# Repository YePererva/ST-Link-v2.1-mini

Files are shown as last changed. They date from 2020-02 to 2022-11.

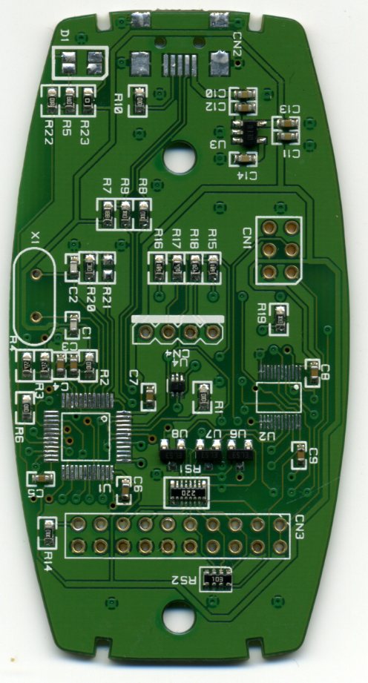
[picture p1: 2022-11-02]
references/project-of-other/top.jpg

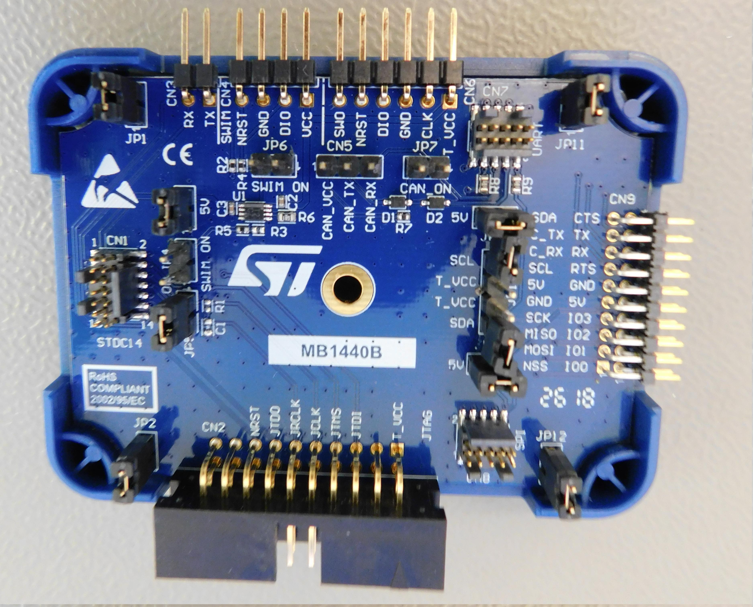
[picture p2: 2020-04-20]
references/St-Link v3/STLink-V3-Board-Large.jpg

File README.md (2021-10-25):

# ST-Link v2.1 - mini

** Status ** : Unfinished and deprecated due to obtaining the [STLink V3 mini](https://www.st.com/en/development-tools/stlink-v3mini.html)

The idea of this project came, when I broke my [NUCLEO-L432KC](https://www.st.com/content/st_com/en/products/evaluation-tools/product-evaluation-tools/mcu-mpu-eval-tools/stm32-mcu-mpu-eval-tools/stm32-nucleo-boards/nucleo-l432kc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) board and thought if I can cannibalize the leftovers of it and make a replacement PCB, where I can transplant the microcontroller and keep using the chip from Nucleo board as a dedicated STLink programmer.

This repository has no purpose or instructions for hacking the firmware or any other part of STLink!

Although, the schematic of original [NUCLEO-L432KC](https://www.st.com/resource/en/data_brief/nucleo-l432kc.pdf) and its STLink part is available [on STMicroelectronics website](https://www.st.com/resource/en/schematic_pack/nucleo-32pins_sch.zip) it has few points that I don't like:
- it uses USB-micro, while USB type C seems to be more appropriate
- STMicroelectronics introduced the `STCD-14` connector for STM32 programming (via SWD + VCP). It would be nice to have it
- official firmware allows to switch device between programming the STM32 and STM8 microcontrollers
- the [Black Magic Probe](https://github.com/blacksphere/blackmagic/wiki) is another popular programming / debugging tool and have a [firmware](https://github.com/blacksphere/blackmagic/tree/master/src/platforms/stlink), compatible with STM32F103CxT6 microcontroller. It may be reasonable to have a programming interface to convert this DIY STLink into BMP later in future.
- can't power-up the target microcontroller from STLink.

## What is inside of repository
- `datasheets`: \
  datasheets for microcontroller, USB type Connector, etc.
- `project files`:
  - `simplified`: \
    simplified version of STLink without EDS protection of either USB or SWD / SWIM / VCP
  - `protected`: \
    version with EDS protection
  - `STDC14-adapters`: \
    The STLink V3 mini can't be connected directly to devboards alike BluePill, etc. due to different connector pinout and size. Here are 2 connectors for STDC14 : as breadboard breakout board and as plug-&-play connector to SWD interface on BluePill board.
- `references`: \
    references on stuff like pinout of programming interfaces, STLinks made by other people, etc.

### Similar projects

- https://github.com/MartinD-CZ/ST-Link-V21-clone

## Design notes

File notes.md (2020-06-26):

# STDC14 as SWD + USART interface
STM suggests SAMTEC FTSH-107-01-L-DV-K-A as STDC14 connector.

Pinout is

| Pin # | Description | Pin # | Description |
| --- | --- | --- | --- |
| 1 | Reserved | 2 | Reserved |
| 3 | Target Vcc | 4 | T_JTMS/T_SWDIO |
| 5 | GND | 6 | T_JRCLK/T_SWCLK |
| 7 | GND | 8 | T_JDIO / T_SWO |
| 9 | T_JRCLK / NC | 10 | T_JTDI / NC |
| 11 | GND detect | 12 | T_NRST |
| 13 | T_VCP_RX (ST_LINK_TX) | 14 | T_VCP_TX (ST_LINK_RX) |

Reserved pins - not connected on target side
Target VCC doesn't provide power to target board. It is ST-link reference to indicate that target is powered.

# STDC14 and 10 Pin Cortex arm debug connector to STM32F103C8T6 BluePill
https://stackoverflow.com/questions/57538832/how-to-connect-stlink-v3mini-to-a-blue-pill

# STDC14 as SWD + UART on target side

| Pin # | Description | Pin # | Description |
| --- | --- | --- | --- |
| 1 | NC | 2 | NC |
| 3 | Vcc | 4 | SWDIO |
| 5 | GND | 6 | SWCLK |
| 7 | GND | 8 | SWO |
| 9 |  NC | 10 | Not connected |
| 11 | Pull to GND 100 Ohm | 12 | NRST |
| 13 | RX | 14 | TX |

`NC` : Not Connected

# STDC14 as SWD + UART on STLINK side

| Pin # | Description | Pin # | Description |
| --- | --- | --- | --- |
| 1 | NC | 2 | NC |
| 3 | Vcc | 4 | SWDIO |
| 5 | GND | 6 | SWCLK |
| 7 | GND | 8 | SWO |
| 9 |  NC | 10 | Not connected |
| 11 | Pull to GND with 100 Ohm | 12 | NRST |
| 13 | TX | 14 | RX |

`NC` : Not Connected

# STDC14 as JTAG

| Pin # | Description | Pin # | Description |
| --- | --- | --- | --- |
| 1 | NC | 2 | NC |
| 3 | Target Vcc | 4 | T_JTMS |
| 5 | GND | 6 | T_JCLK |
| 7 | GND | 8 | T_JDIO |
| 9 | T_JRCLK | 10 | T_JTDI |
| 11 | Pull to GND with 100 Ohm | 12 | T_NRST |
| 13 | NC | 14 | NC |

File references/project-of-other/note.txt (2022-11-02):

Schematic has mistake: R1 should got to GND, not 3.3V

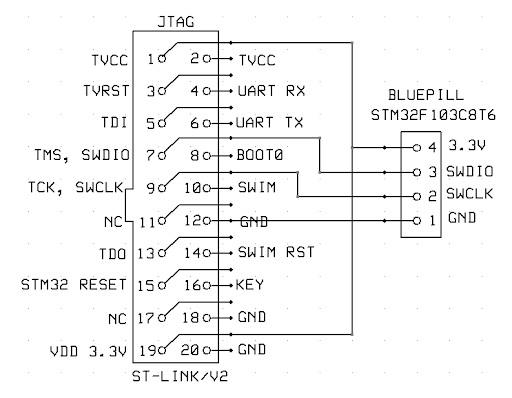
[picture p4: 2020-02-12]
references/JTAG/JTAG to BluePill.png

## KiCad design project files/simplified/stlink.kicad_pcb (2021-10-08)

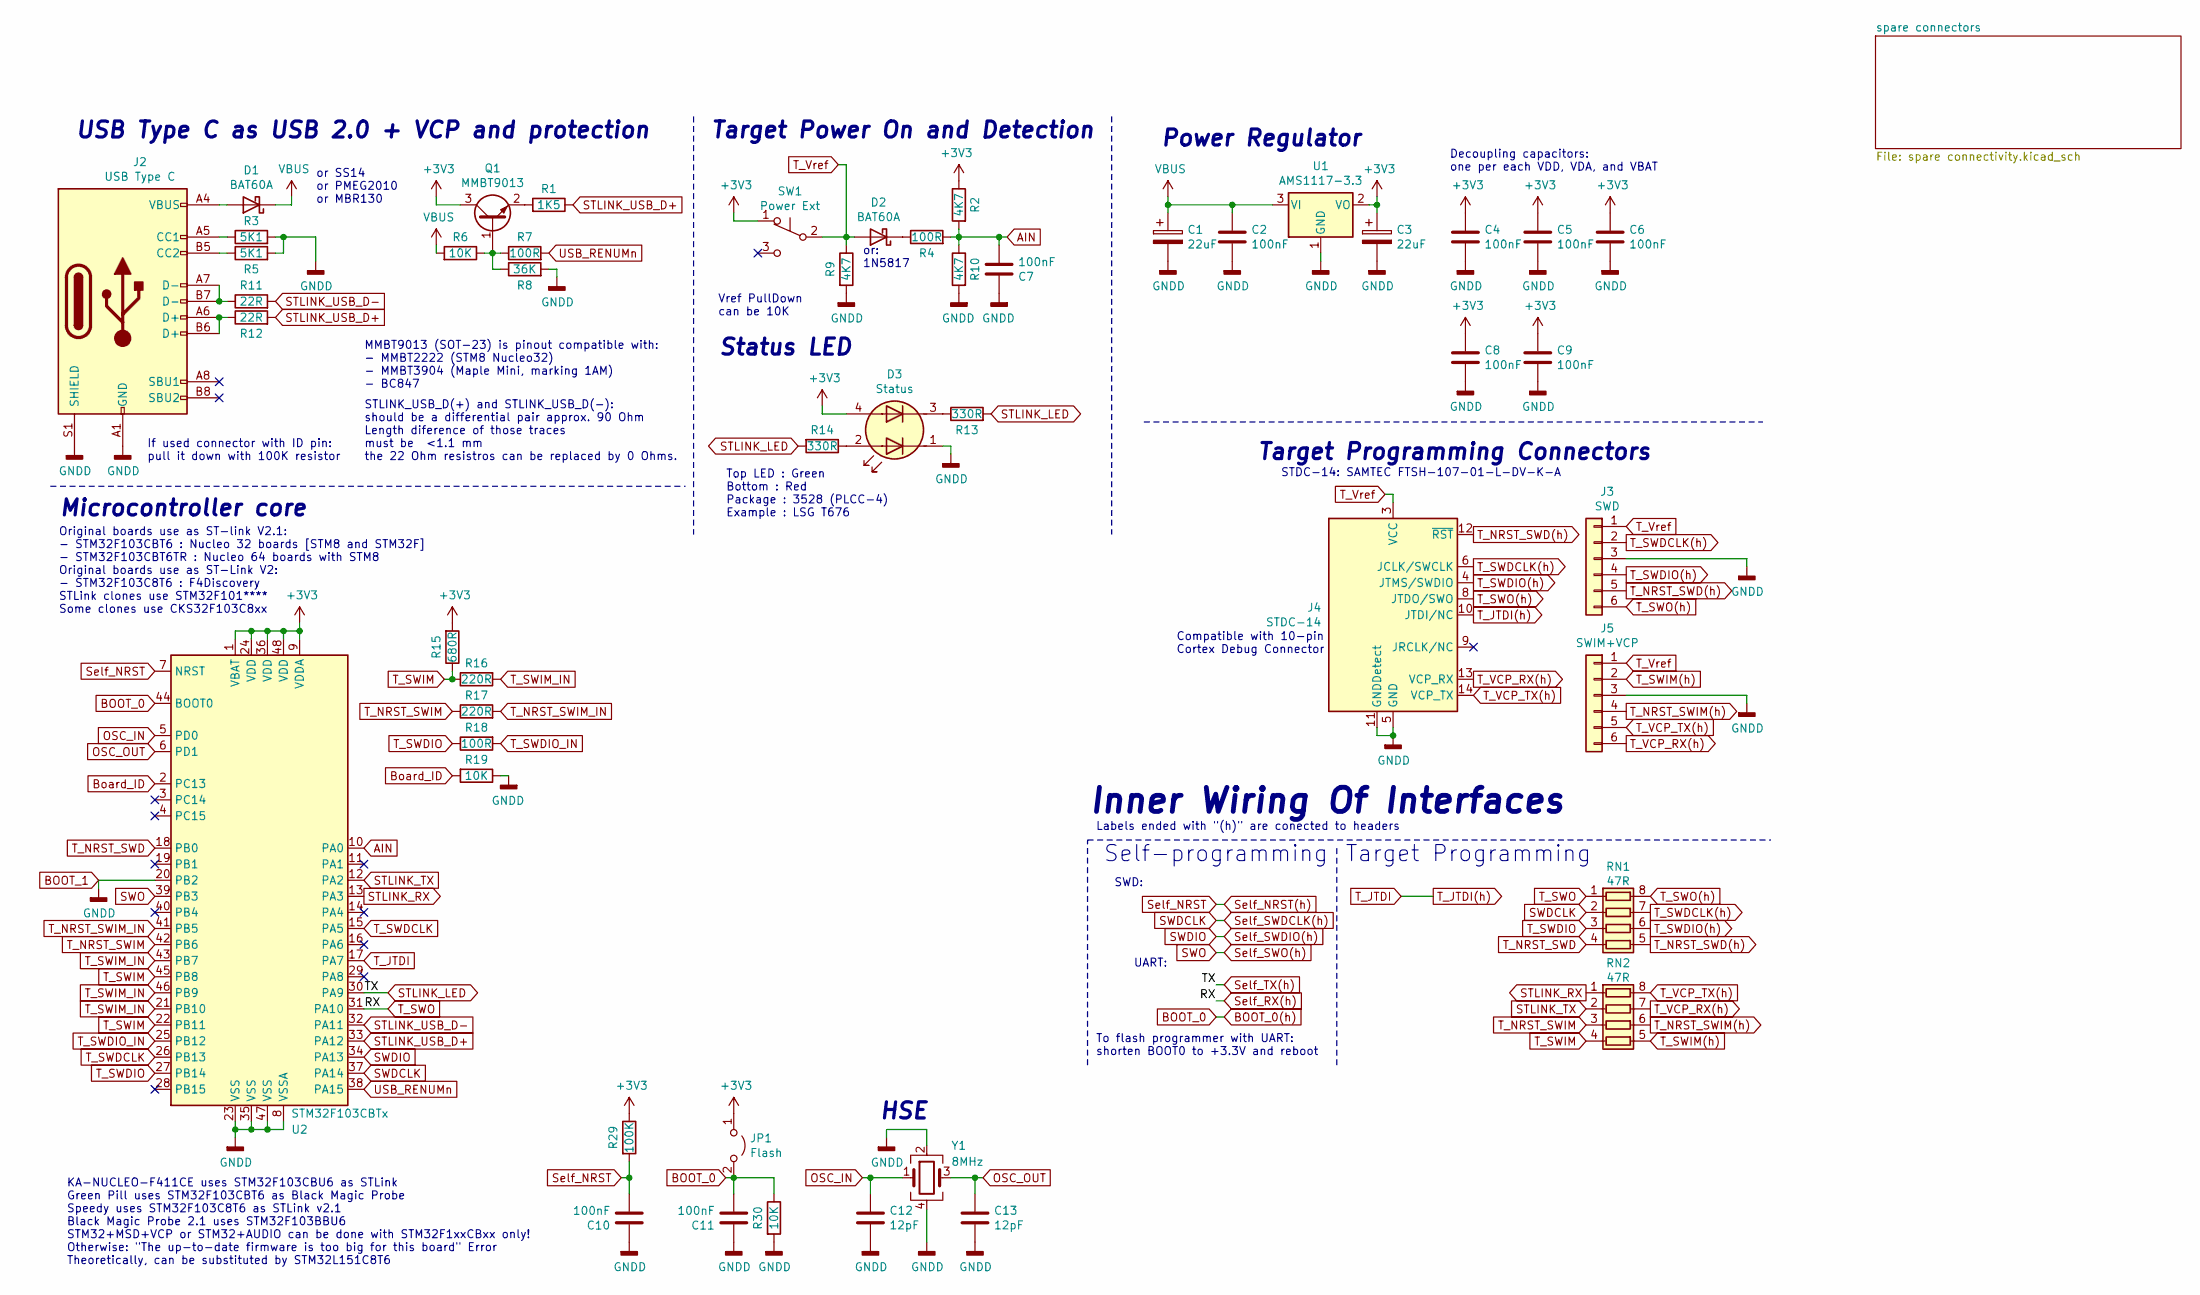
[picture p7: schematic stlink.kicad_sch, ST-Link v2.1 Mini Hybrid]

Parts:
C1, C3: 22uF; CP_EIA-7343-30_AVX-N
C2, C4, C5, C6, C7, C8, C9, C10, C11: 100nF; C_0603_1608Metric
C12, C13: 12pF; C_0603_1608Metric
D1, D2: BAT60A; D_SOD-323
D3: Status; LED_Avago_PLCC4_3.2x2.8mm_CW
J2: USB Type C; USB_C_Receptacle_Palconn_UTC16-G
J3: SWD; PinHeader_1x06_P2.54mm_Vertical
J4: STDC-14; PinHeader_2x07_P1.27mm_Vertical_SMD
J5: SWIM+VCP; PinHeader_1x06_P2.54mm_Vertical
JP1: Flash; PinSocket_2x01_P1.27mm_Vertical
Q1: MMBT9013; SOT-23
R1: 1K5; R_0603_1608Metric
R2, R9, R10: 4K7; R_0603_1608Metric
R3, R5: 5K1; R_0603_1608Metric
R4, R7, R18: 100R; R_0603_1608Metric
R6, R19, R30: 10K; R_0603_1608Metric
R8: 36K; R_0603_1608Metric
R11, R12: 22R; R_0603_1608Metric
R13, R14: 330R; R_0603_1608Metric
R15: 680R; R_0603_1608Metric
R16, R17: 220R; R_0603_1608Metric
R29: 100K; R_0603_1608Metric
RN1, RN2: 47R
SW1: Power Ext
U1: AMS1117-3.3; SOT-223-3_TabPin2
U2: STM32F103CBTx; LQFP-48_7x7mm_P0.5mm
Y1: 8MHz; Crystal_SMD_Abracon_ABM8G-4Pin_3.2x2.5mm

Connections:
AIN: C7.2, R2.2, R4.2, R10.1, U2.10 (PA0); also elsewhere on the board
BOOT_0: C11.2, JP1.2 (B), R30.1, U2.44 (BOOT0); also elsewhere on the board
BOOT_1: C1.2, C2.2, C3.2, C4.2, C5.2, C6.2, C7.1, C8.2, C9.2, C10.1, C11.1, C12.2, C13.2, D3.1 (A1), J2.A1 (GND), J2.A12 (GND), J2.B1 (GND), J2.B12 (GND), J2.S1 (SHIELD), J3.3, J4.5 (GND), J4.7 (GND), J4.11 (GNDDetect), J5.3, R3.2, R5.2, R8.2, R9.2, R10.2, R19.1, R30.2, U1.1 (GND), U2.8 (VSSA), U2.20 (PB2), U2.23 (VSS), U2.35 (VSS), U2.47 (VSS), Y1.2, Y1.4; also elsewhere on the board
Board_ID: R19.2, U2.2 (PC13); also elsewhere on the board
unnamed: D1.2 (A), J2.A4 (VBUS), J2.A9 (VBUS), J2.B4 (VBUS), J2.B9 (VBUS)
unnamed: D2.1 (K), R4.1
unnamed: D3.2 (K1), R14.1
unnamed: D3.3 (A2), R13.1
unnamed: J2.A5 (CC1), R3.1
unnamed: J2.A6 (D+), J2.B6 (D+), R12.1
unnamed: J2.A7 (D-), J2.B7 (D-), R11.1
unnamed: J2.B5 (CC2), R5.1
unnamed: Q1.1 (B), R6.1, R7.1, R8.1
unnamed: Q1.2 (E), R1.2
OSC_IN: C12.1, U2.5 (PD0), Y1.1; also elsewhere on the board
OSC_OUT: C13.1, U2.6 (PD1), Y1.3; also elsewhere on the board
STLINK_LED: R13.2, R14.2, U2.30 (PA9); also elsewhere on the board
STLINK_RX: RN2.1 (R1.1), U2.13 (PA3); also elsewhere on the board
STLINK_TX: RN2.2 (R2.1), U2.12 (PA2); also elsewhere on the board
STLINK_USB_D+: R1.1, R12.2, U2.33 (PA12); also elsewhere on the board
STLINK_USB_D-: R11.2, U2.32 (PA11); also elsewhere on the board
SWDCLK: RN1.2 (R2.1), U2.37 (PA14); also elsewhere on the board
SWDIO: U2.34 (PA13); also elsewhere on the board
SWO: U2.39 (PB3); also elsewhere on the board
Self_NRST: C10.2, R29.2, U2.7 (NRST); also elsewhere on the board
Self_RX(h): RN1.1 (R1.1), U2.31 (PA10); also elsewhere on the board
T_JTDI: J4.10 (JTDI/NC), U2.17 (PA7); also elsewhere on the board
T_NRST_SWD: RN1.4 (R4.1), U2.18 (PB0); also elsewhere on the board
T_NRST_SWD(h): J3.5, J4.12 (~RST), RN1.5 (R4.2)
T_NRST_SWIM: R17.1, RN2.3 (R3.1), U2.42 (PB6); also elsewhere on the board
T_NRST_SWIM(h): J5.4, RN2.6 (R3.2)
T_NRST_SWIM_IN: R17.2, U2.41 (PB5); also elsewhere on the board
T_SWDCLK: U2.15 (PA5), U2.26 (PB13); also elsewhere on the board
T_SWDCLK(h): J3.2, J4.6 (JCLK/SWCLK), RN1.7 (R2.2)
T_SWDIO: R18.1, RN1.3 (R3.1), U2.27 (PB14); also elsewhere on the board
T_SWDIO(h): J3.4, J4.4 (JTMS/SWDIO), RN1.6 (R3.2)
T_SWDIO_IN: R18.2, U2.25 (PB12); also elsewhere on the board
T_SWIM: R15.1, R16.1, RN2.4 (R4.1), U2.22 (PB11), U2.45 (PB8); also elsewhere on the board
T_SWIM(h): J5.2, RN2.5 (R4.2)
T_SWIM_IN: R16.2, U2.21 (PB10), U2.43 (PB7), U2.46 (PB9); also elsewhere on the board
T_SWO(h): J3.6, J4.8 (JTDO/SWO), RN1.8 (R1.2)
T_VCP_RX(h): J4.13 (VCP_RX), J5.6, RN2.7 (R2.2)
T_VCP_TX(h): J4.14 (VCP_TX), J5.5, RN2.8 (R1.2)
T_Vref: D2.2 (A), J3.1, J4.3 (VCC), J5.1, R9.1, SW1.2 (B)
USB_RENUMn: R7.2, U2.38 (PA15); also elsewhere on the board
VBUS: C1.1, C2.1, D1.1 (K), R6.2, U1.3 (VI)

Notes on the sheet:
Microcontroller core
Original boards use as ST-link V2.1: - STM32F103CBT6 : Nucleo 32 boards [STM8 and STM32F] - STM32F103CBT6TR : Nucleo 64 boards with STM8 Original boards use as ST-Link V2: - STM32F103C8T6 : F4Discovery STLink clones use STM32F101**** Some clones use CKS32F103C8xx
KA-NUCLEO-F411CE uses STM32F103CBU6 as STLink Green Pill uses STM32F103CBT6 as Black Magic Probe Speedy uses STM32F103C8T6 as STLink v2.1 Black Magic Probe 2.1 uses STM32F103BBU6 STM32+MSD+VCP or STM32+AUDIO can be done with STM32F1xxCBxx only! Otherwise: "The up-to-date firmware is too big for thi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
USB Type C as USB 2.0 + VCP and protection
If used connector with ID pin: pull it down with 100K resistor
or SS14 or PMEG2010 or MBR130
MMBT9013 (SOT-23) is pinout compatible with: - MMBT2222 (STM8 Nucleo32) - MMBT3904 (Maple Mini, marking 1AM) - BC847
STLINK_USB_D(+) and STLINK_USB_D(-): should be a differential pair approx. 90 Ohm Length diference of those traces must be <1.1 mm the 22 Ohm resistros can be replaced by 0 Ohms.
Target Power On and Detection
Vref PullDown can be 10K
Status LED
Top LED : Green Bottom : Red Package : 3528 (PLCC-4) Example : LSG T676
or: 1N5817
HSE
Inner Wiring Of Interfaces
Labels ended with "(h)" are conected to headers
To flash programmer with UART: shorten BOOT0 to +3.3V and reboot
SWD:
Power Regulator
UART:
Compatible with 10-pin Cortex Debug Connector
Target Programming Connectors
STDC-14: SAMTEC FTSH-107-01-L-DV-K-A
Self-programming
Target Programming
Decoupling capacitors: one per each VDD, VDA, and VBAT

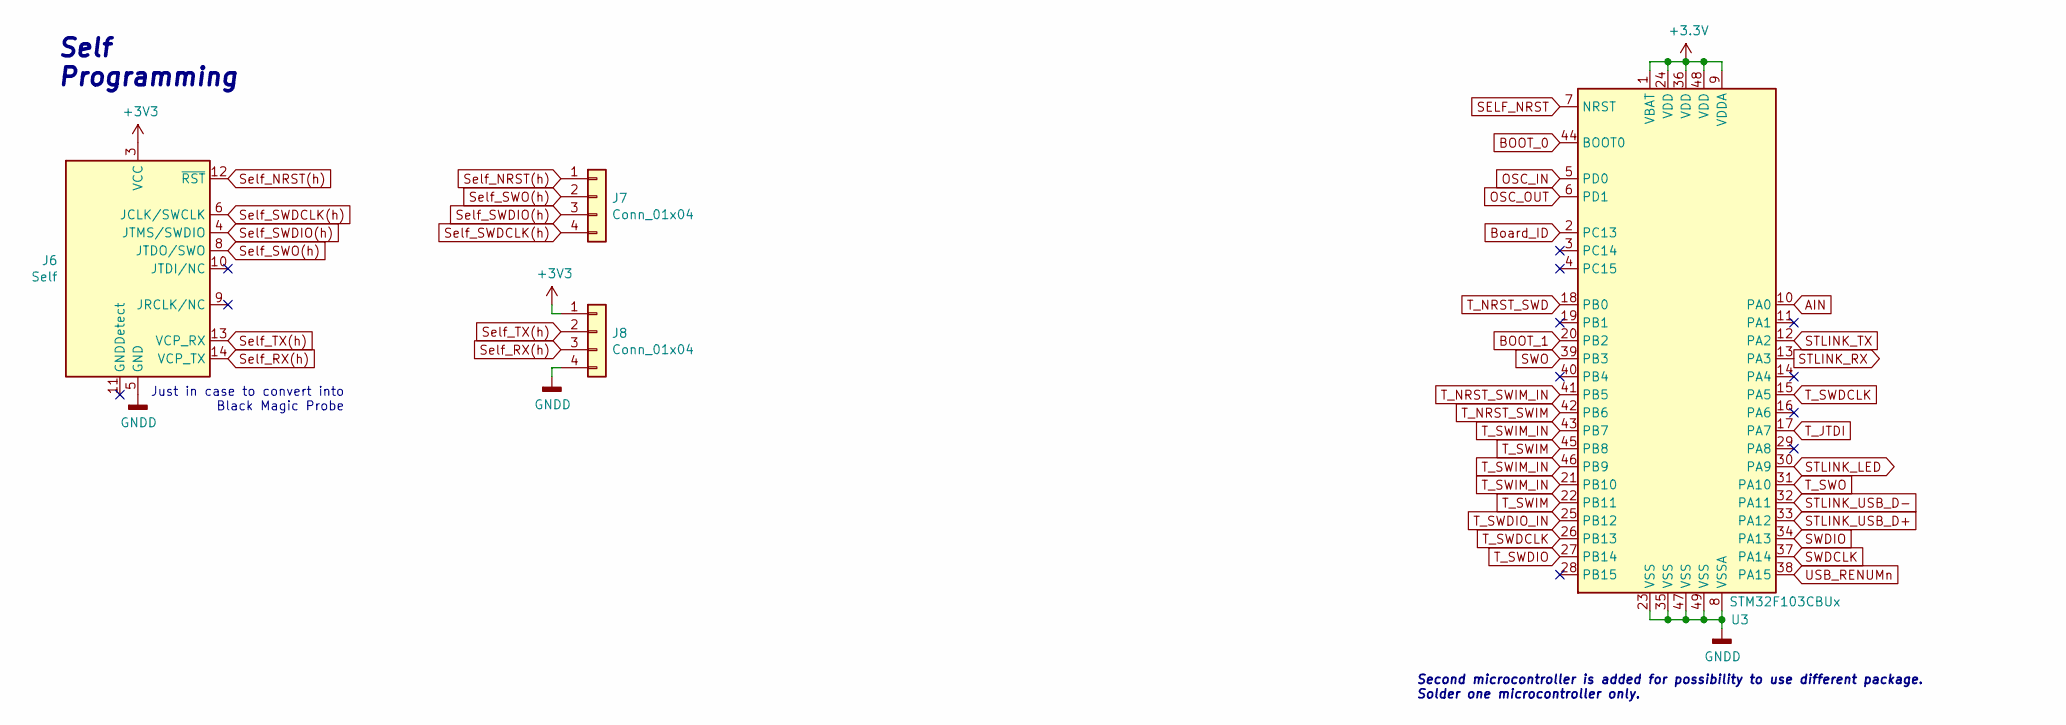
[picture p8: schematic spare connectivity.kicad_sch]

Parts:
J6: Self; PinHeader_2x07_P1.27mm_Vertical_SMD
J7, J8: Conn_01x04; PinHeader_1x04_P2.54mm_Vertical
U3: STM32F103CBUx; QFN-48-1EP_7x7mm_P0.5mm_EP5.6x5.6mm

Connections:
AIN: U3.10 (PA0); also elsewhere on the board
BOOT_0: U3.44 (BOOT0); also elsewhere on the board
BOOT_1: J6.5 (GND), J6.7 (GND), J8.4, U3.8 (VSSA), U3.20 (PB2), U3.23 (VSS), U3.35 (VSS), U3.47 (VSS), U3.49 (VSS); also elsewhere on the board
Board_ID: U3.2 (PC13); also elsewhere on the board
OSC_IN: U3.5 (PD0); also elsewhere on the board
OSC_OUT: U3.6 (PD1); also elsewhere on the board
SELF_NRST: U3.7 (NRST)
STLINK_LED: J6.13 (VCP_RX), J8.2, U3.30 (PA9); also elsewhere on the board
STLINK_RX: U3.13 (PA3); also elsewhere on the board
STLINK_TX: U3.12 (PA2); also elsewhere on the board
STLINK_USB_D+: U3.33 (PA12); also elsewhere on the board
STLINK_USB_D-: U3.32 (PA11); also elsewhere on the board
SWDCLK: J6.6 (JCLK/SWCLK), J7.4, U3.37 (PA14); also elsewhere on the board
SWDIO: J6.4 (JTMS/SWDIO), J7.3, U3.34 (PA13); also elsewhere on the board
SWO: J6.8 (JTDO/SWO), J7.2, U3.39 (PB3); also elsewhere on the board
Self_NRST: J6.12 (~RST), J7.1; also elsewhere on the board
Self_RX(h): J6.14 (VCP_TX), J8.3, U3.31 (PA10); also elsewhere on the board
T_JTDI: U3.17 (PA7); also elsewhere on the board
T_NRST_SWD: U3.18 (PB0); also elsewhere on the board
T_NRST_SWIM: U3.42 (PB6); also elsewhere on the board
T_NRST_SWIM_IN: U3.41 (PB5); also elsewhere on the board
T_SWDCLK: U3.15 (PA5), U3.26 (PB13); also elsewhere on the board
T_SWDIO: U3.27 (PB14); also elsewhere on the board
T_SWDIO_IN: U3.25 (PB12); also elsewhere on the board
T_SWIM: U3.22 (PB11), U3.45 (PB8); also elsewhere on the board
T_SWIM_IN: U3.21 (PB10), U3.43 (PB7), U3.46 (PB9); also elsewhere on the board
USB_RENUMn: U3.38 (PA15); also elsewhere on the board

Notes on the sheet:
Self Programming
Just in case to convert into Black Magic Probe
Second microcontroller is added for possibility to use different package. Solder one microcontroller only.

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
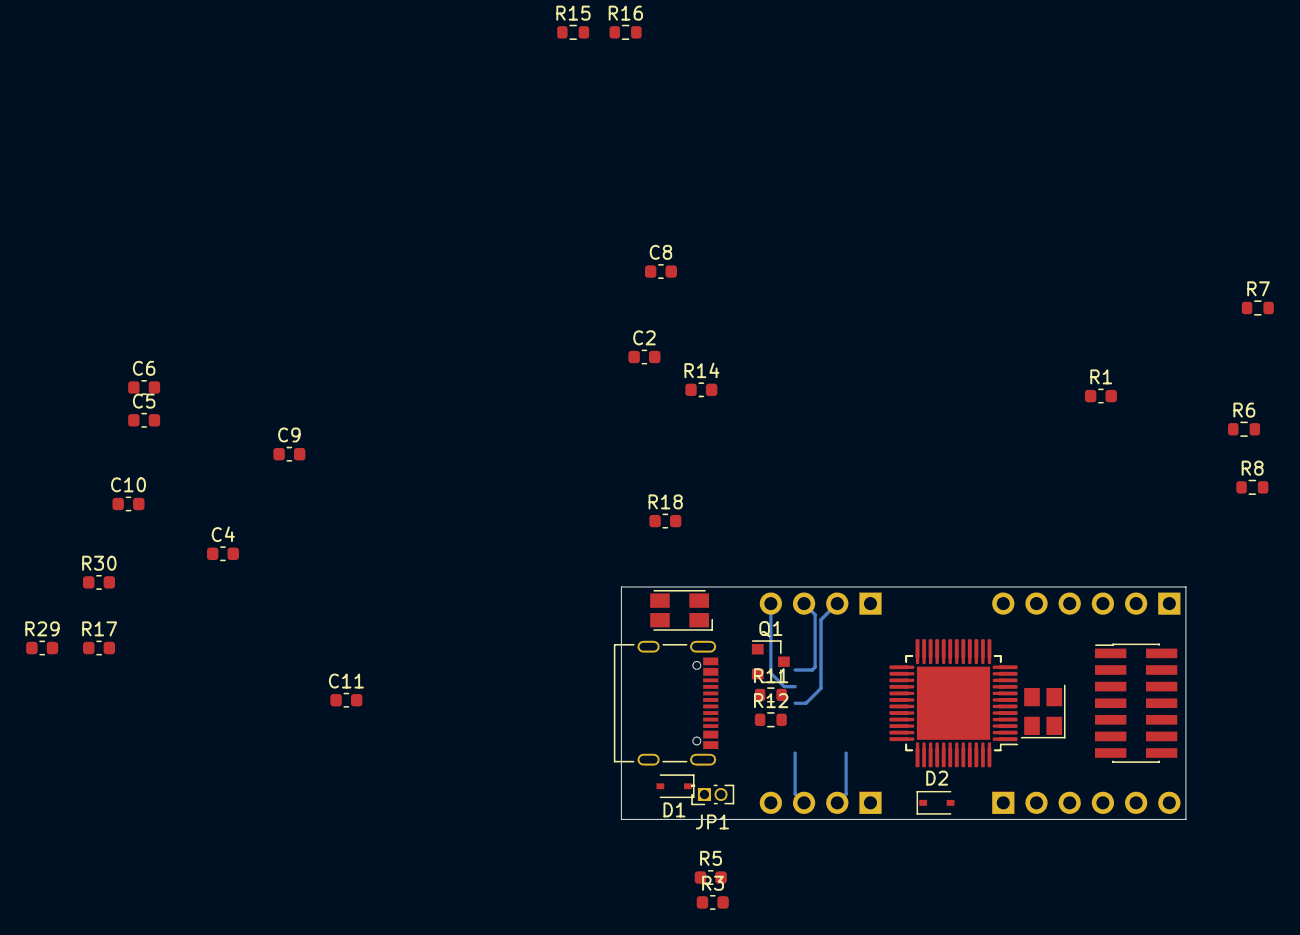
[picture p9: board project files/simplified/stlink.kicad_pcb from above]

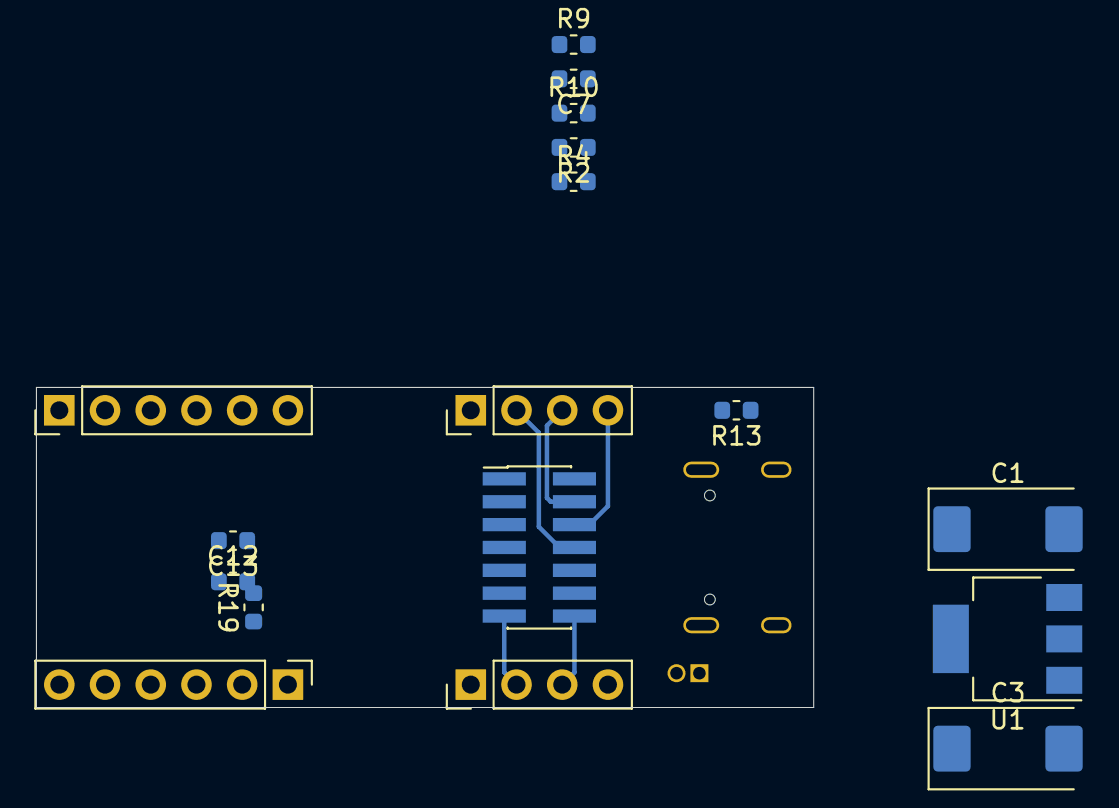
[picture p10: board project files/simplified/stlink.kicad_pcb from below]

Board: 2 copper layers, 43.2 x 17.8 mm, 50 parts (17 on the bottom side), 45 nets.

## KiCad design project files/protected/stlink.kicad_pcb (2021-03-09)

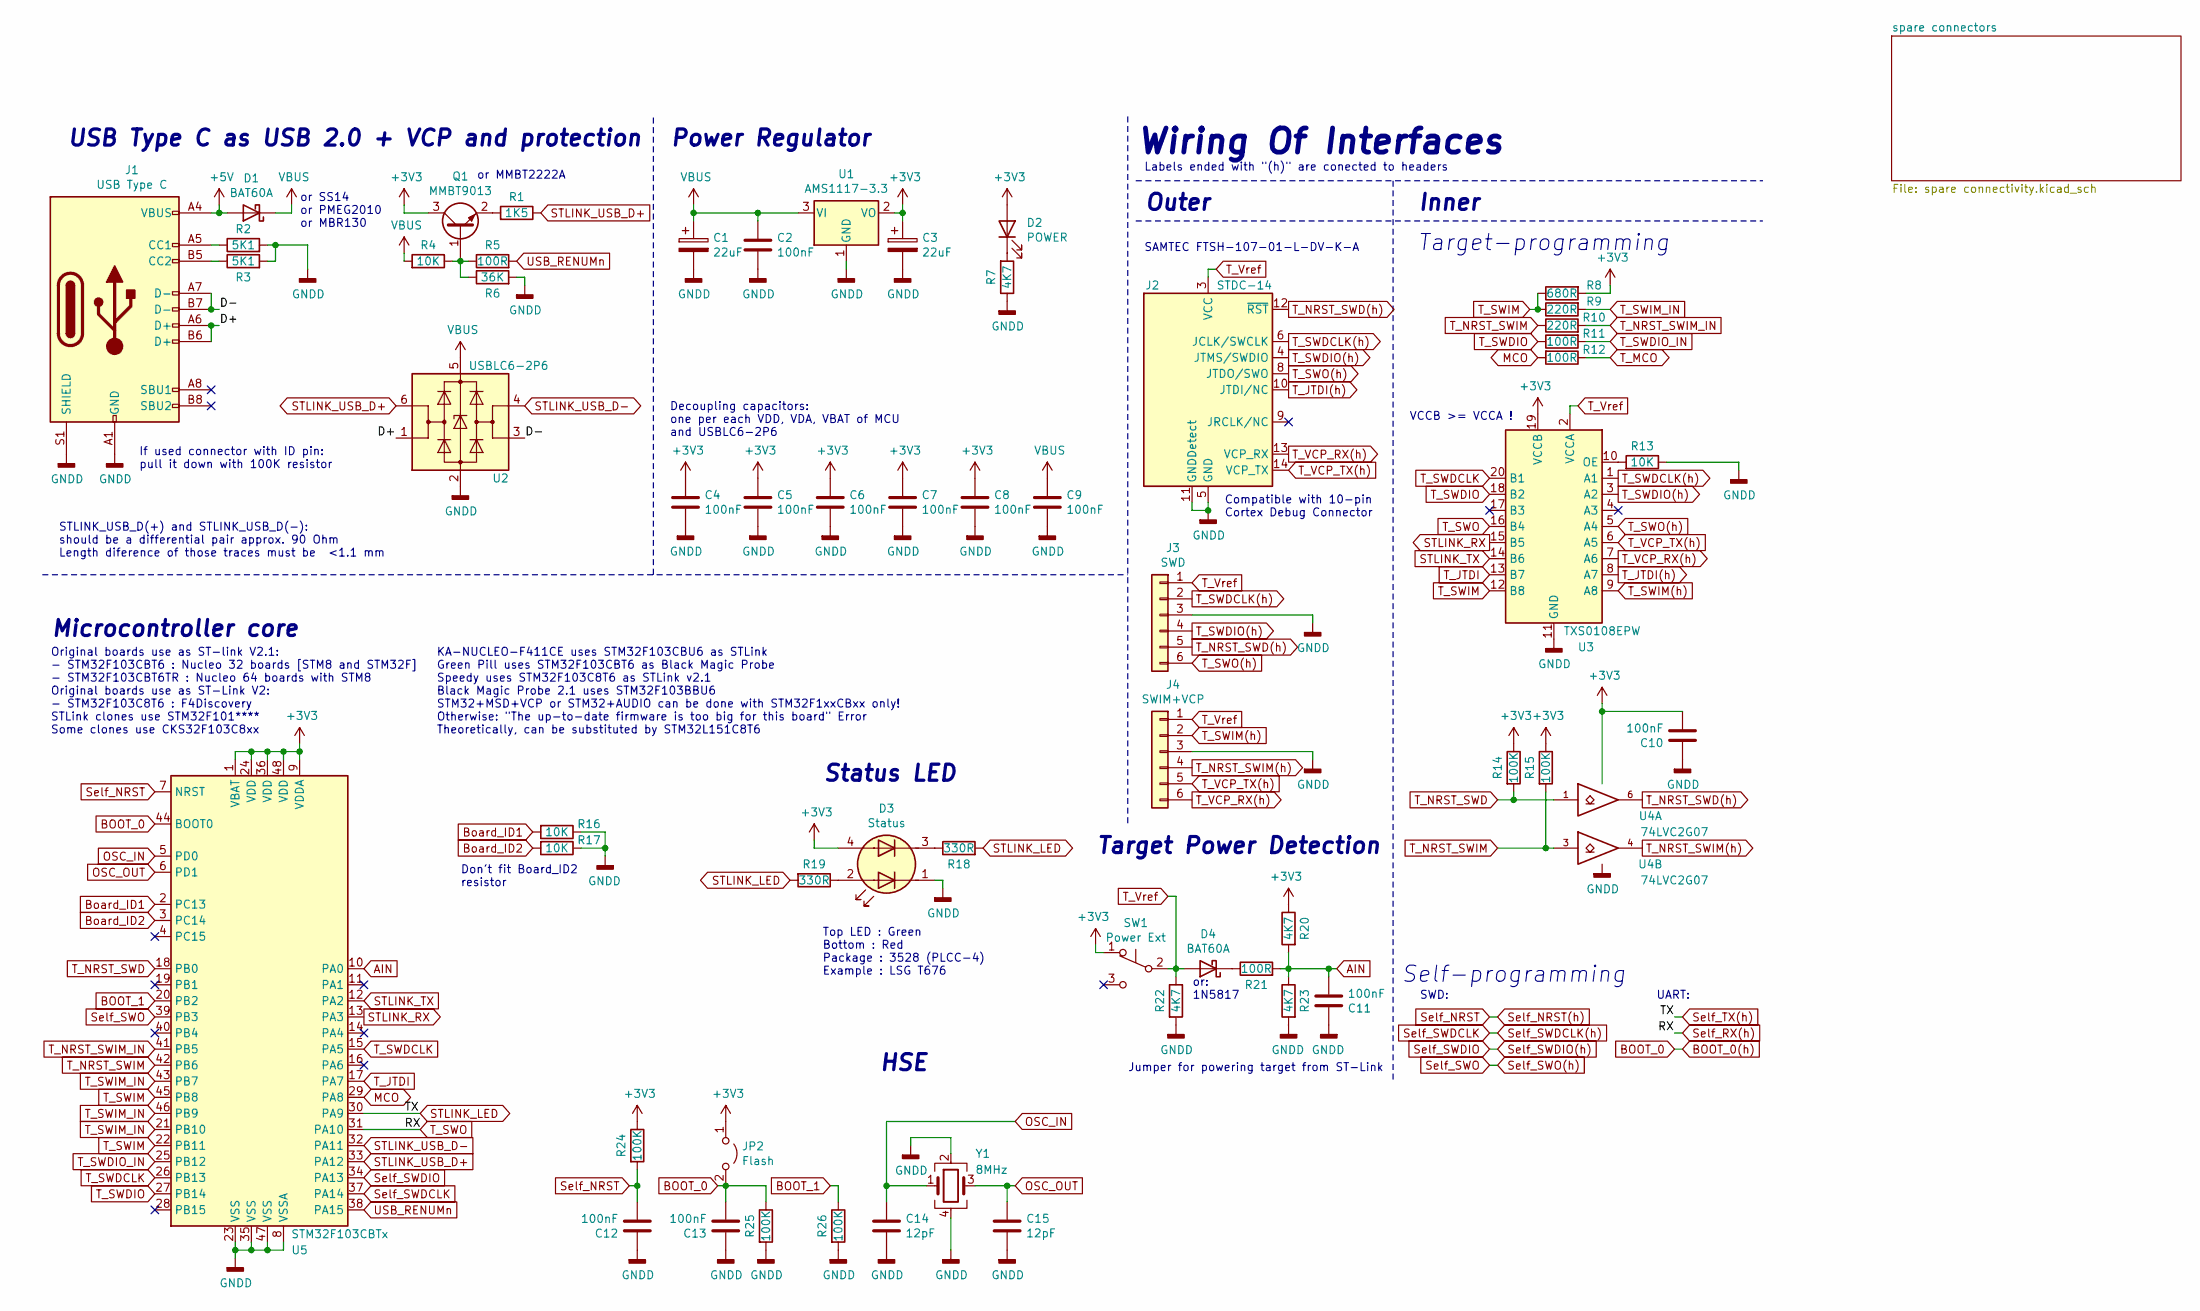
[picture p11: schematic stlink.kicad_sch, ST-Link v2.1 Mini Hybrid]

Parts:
C1, C3: 22uF; CP_EIA-7343-30_AVX-N
C2, C4, C5, C6, C7, C8, C9, C10, C11, C12, C13: 100nF; C_0603_1608Metric
C14, C15: 12pF; C_0603_1608Metric
D1, D4: BAT60A; D_SOD-323
D2: POWER; LED_0805_2012Metric_Castellated
D3: Status; LED_Avago_PLCC4_3.2x2.8mm_CW
J1: USB Type C; USB_C_Receptacle_Palconn_UTC16-G
J2: STDC-14; PinHeader_2x07_P1.27mm_Vertical_SMD
J3: SWD; PinHeader_1x06_P2.54mm_Vertical
J4: SWIM+VCP; PinHeader_1x06_P2.54mm_Vertical
JP2: Flash; PinSocket_2x01_P1.27mm_Vertical
Q1: MMBT9013; SOT-23
R1: 1K5; R_0603_1608Metric
R2, R3: 5K1; R_0603_1608Metric
R4, R13, R16, R17: 10K; R_0603_1608Metric
R5, R11, R12, R21: 100R; R_0603_1608Metric
R6: 36K; R_0603_1608Metric
R7, R20, R22, R23: 4K7; R_0603_1608Metric
R8: 680R; R_0603_1608Metric
R9, R10: 220R; R_0603_1608Metric
R14, R15, R24, R25, R26: 100K; R_0603_1608Metric
R18, R19: 330R; R_0603_1608Metric
SW1: Power Ext; SW_SPDT_PCM12
U1: AMS1117-3.3; SOT-223-3_TabPin2
U2: USBLC6-2P6; SOT-666
U3: TXS0108EPW; TSSOP-20_4.4x6.5mm_P0.65mm
U4: 74LVC2G07; SOT-363_SC-70-6
U5: STM32F103CBTx; LQFP-48_7x7mm_P0.5mm
Y1: 8MHz; Crystal_SMD_Abracon_ABM8G-4Pin_3.2x2.5mm

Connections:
+5V: D1.2 (A), J1.A4 (VBUS), J1.A9 (VBUS), J1.B4 (VBUS), J1.B9 (VBUS)
/D+: J1.A6 (D+), J1.B6 (D+), U2.1 (I/O1)
/D-: J1.A7 (D-), J1.B7 (D-), U2.3 (I/O2)
AIN: C11.2, R20.2, R21.2, R23.1, U5.10 (PA0); also elsewhere on the board
BOOT_0: C13.2, JP2.2 (B), R25.1, U5.44 (BOOT0); also elsewhere on the board
BOOT_1: R26.1, U5.20 (PB2); also elsewhere on the board
Board_ID1: R16.2, U5.2 (PC13); also elsewhere on the board
Board_ID2: R17.2, U5.3 (PC14); also elsewhere on the board
GND: C1.2, C2.2, C3.2, C4.2, C5.2, C6.2, C7.2, C8.2, C9.2, C10.1, C11.1, C12.1, C13.1, C14.2, C15.2, D3.1 (A1), J1.A1 (GND), J1.A12 (GND), J1.B1 (GND), J1.B12 (GND), J1.S1 (SHIELD), J2.5 (GND), J2.7 (GND), J2.11 (GNDDetect), J3.3, J4.3, R2.2, R3.2, R6.2, R7.1, R13.1, R16.1, R17.1, R22.2, R23.2, R25.2, R26.2, U1.1 (GND), U2.2 (GND), U3.11 (GND), U4.2 (GND), U5.8 (VSSA), U5.23 (VSS), U5.35 (VSS), U5.47 (VSS), Y1.2, Y1.4; also elsewhere on the board
MCO: R12.2, U5.29 (PA8); also elsewhere on the board
unnamed: D2.1 (K), R7.2
unnamed: D3.2 (K1), R19.1
unnamed: D3.3 (A2), R18.1
unnamed: D4.1 (K), R21.1
unnamed: J1.A5 (CC1), R2.1
unnamed: J1.B5 (CC2), R3.1
unnamed: Q1.1 (B), R4.1, R5.1, R6.1
unnamed: Q1.2 (E), R1.2
unnamed: R13.2, U3.10 (OE)
OSC_IN: C14.1, U5.5 (PD0), Y1.1; also elsewhere on the board
OSC_OUT: C15.1, U5.6 (PD1), Y1.3; also elsewhere on the board
STLINK_LED: R18.2, R19.2, U5.30 (PA9); also elsewhere on the board
STLINK_RX: U3.15 (B5), U5.13 (PA3); also elsewhere on the board
STLINK_TX: U3.14 (B6), U5.12 (PA2); also elsewhere on the board
STLINK_USB_D+: R1.1, U2.6 (I/O1), U5.33 (PA12); also elsewhere on the board
STLINK_USB_D-: U2.4 (I/O2), U5.32 (PA11); also elsewhere on the board
Self_NRST: C12.2, R24.2, U5.7 (NRST); also elsewhere on the board
Self_RX(h): U3.16 (B4), U5.31 (PA10); also elsewhere on the board
Self_SWDCLK: U5.37 (PA14); also elsewhere on the board
Self_SWDIO: U5.34 (PA13); also elsewhere on the board
Self_SWO: U5.39 (PB3); also elsewhere on the board
T_JTDI: U3.13 (B7), U5.17 (PA7); also elsewhere on the board
T_JTDI(h): J2.10 (JTDI/NC), U3.8 (A7)
T_MCO: R12.1
T_NRST_SWD: R14.2, U4.1, U5.18 (PB0); also elsewhere on the board
T_NRST_SWD(h): J2.12 (~RST), J3.5, U4.6
T_NRST_SWIM: R10.1, R15.2, U4.3, U5.42 (PB6); also elsewhere on the board
T_NRST_SWIM(h): J4.4, U4.4
T_NRST_SWIM_IN: R10.2, U5.41 (PB5); also elsewhere on the board
T_SWDCLK: U3.20 (B1), U5.15 (PA5), U5.26 (PB13); also elsewhere on the board
T_SWDCLK(h): J2.6 (JCLK/SWCLK), J3.2, U3.1 (A1)
T_SWDIO: R11.1, U3.18 (B2), U5.27 (PB14); also elsewhere on the board
T_SWDIO(h): J2.4 (JTMS/SWDIO), J3.4, U3.3 (A2)
T_SWDIO_IN: R11.2, U5.25 (PB12); also elsewhere on the board
T_SWIM: R8.1, R9.1, U3.12 (B8), U5.22 (PB11), U5.45 (PB8); also elsewhere on the board
T_SWIM(h): J4.2, U3.9 (A8)
T_SWIM_IN: R9.2, U5.21 (PB10), U5.43 (PB7), U5.46 (PB9); also elsewhere on the board
T_SWO(h): J2.8 (JTDO/SWO), J3.6, U3.5 (A4)
T_VCP_RX(h): J2.13 (VCP_RX), J4.6, U3.7 (A6)
T_VCP_TX(h): J2.14 (VCP_TX), J4.5, U3.6 (A5)
T_Vref: D4.2 (A), J2.3 (VCC), J3.1, J4.1, R22.1, SW1.2 (B), U3.2 (VCCA)
USB_RENUMn: R5.2, U5.38 (PA15); also elsewhere on the board
VBUS: C1.1, C2.1, C9.1, D1.1 (K), R4.2, U1.3 (VI), U2.5 (VBUS)

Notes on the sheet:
Microcontroller core
Original boards use as ST-link V2.1: - STM32F103CBT6 : Nucleo 32 boards [STM8 and STM32F] - STM32F103CBT6TR : Nucleo 64 boards with STM8 Original boards use as ST-Link V2: - STM32F103C8T6 : F4Discovery STLink clones use STM32F101**** Some clones use CKS32F103C8xx
STLINK_USB_D(+) and STLINK_USB_D(-): should be a differential pair approx. 90 Ohm Length diference of those traces must be <1.1 mm
USB Type C as USB 2.0 + VCP and protection
If used connector with ID pin: pull it down with 100K resistor
or SS14 or PMEG2010 or MBR130
KA-NUCLEO-F411CE uses STM32F103CBU6 as STLink Green Pill uses STM32F103CBT6 as Black Magic Probe Speedy uses STM32F103C8T6 as STLink v2.1 Black Magic Probe 2.1 uses STM32F103BBU6 STM32+MSD+VCP or STM32+AUDIO can be done with STM32F1xxCBxx only! Otherwise: "The up-to-date firmware is too big for thi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
Don't fit Board_ID2 resistor
or MMBT2222A
Power Regulator
Decoupling capacitors: one per each VDD, VDA, VBAT of MCU and USBLC6-2P6
Status LED
Top LED : Green Bottom : Red Package : 3528 (PLCC-4) Example : LSG T676
HSE
Target Power Detection
Jumper for powering target from ST-Link
Wiring Of Interfaces
Labels ended with "(h)" are conected to headers
Outer
SAMTEC FTSH-107-01-L-DV-K-A
or: 1N5817
Compatible with 10-pin Cortex Debug Connector
Self-programming
VCCB >= VCCA !
Inner
Target-programming
SWD:
UART:

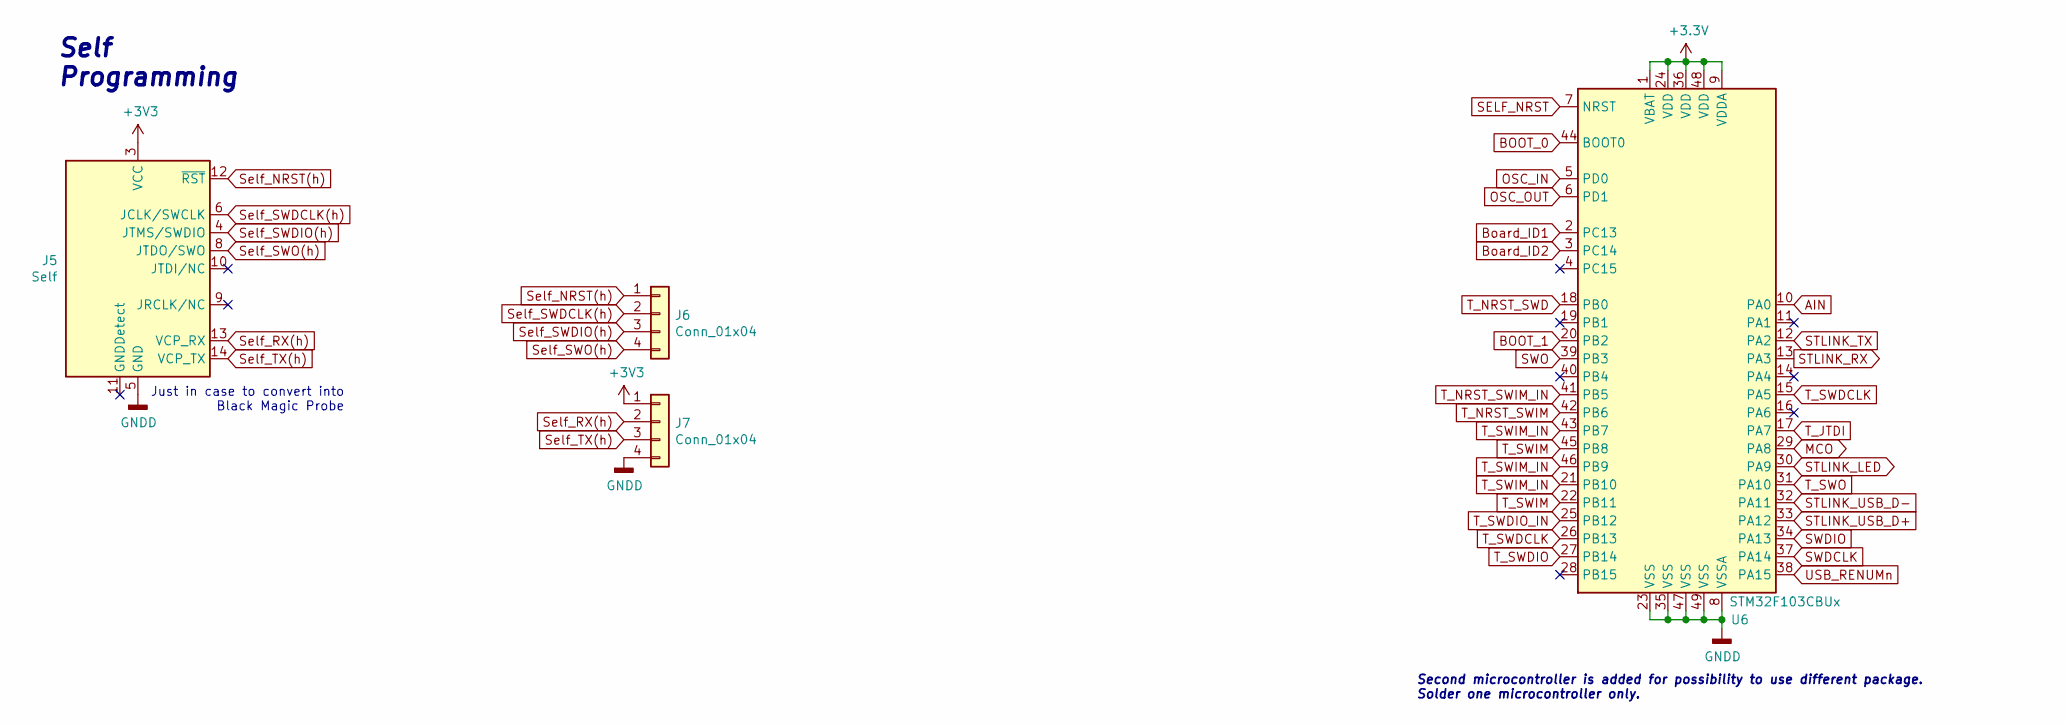
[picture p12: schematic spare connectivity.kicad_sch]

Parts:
J5: Self; PinHeader_2x07_P1.27mm_Vertical_SMD
J6, J7: Conn_01x04; PinSocket_1x04_P2.54mm_Vertical
U6: STM32F103CBUx; QFN-48-1EP_7x7mm_P0.5mm_EP5.6x5.6mm

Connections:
AIN: U6.10 (PA0); also elsewhere on the board
BOOT_0: U6.44 (BOOT0); also elsewhere on the board
BOOT_1: U6.20 (PB2); also elsewhere on the board
Board_ID1: U6.2 (PC13); also elsewhere on the board
Board_ID2: U6.3 (PC14); also elsewhere on the board
GND: J5.5 (GND), J5.7 (GND), J7.4, U6.8 (VSSA), U6.23 (VSS), U6.35 (VSS), U6.47 (VSS), U6.49 (VSS); also elsewhere on the board
MCO: U6.29 (PA8); also elsewhere on the board
OSC_IN: U6.5 (PD0); also elsewhere on the board
OSC_OUT: U6.6 (PD1); also elsewhere on the board
SELF_NRST: U6.7 (NRST)
STLINK_LED: J5.14 (VCP_TX), J7.3, U6.30 (PA9); also elsewhere on the board
STLINK_RX: U6.13 (PA3); also elsewhere on the board
STLINK_TX: U6.12 (PA2); also elsewhere on the board
STLINK_USB_D+: U6.33 (PA12); also elsewhere on the board
STLINK_USB_D-: U6.32 (PA11); also elsewhere on the board
SWDCLK: U6.37 (PA14)
SWDIO: U6.34 (PA13)
SWO: U6.39 (PB3)
Self_NRST: J5.12 (~RST), J6.1; also elsewhere on the board
Self_RX(h): J5.13 (VCP_RX), J7.2, U6.31 (PA10); also elsewhere on the board
Self_SWDCLK: J5.6 (JCLK/SWCLK), J6.2; also elsewhere on the board
Self_SWDIO: J5.4 (JTMS/SWDIO), J6.3; also elsewhere on the board
Self_SWO: J5.8 (JTDO/SWO), J6.4; also elsewhere on the board
T_JTDI: U6.17 (PA7); also elsewhere on the board
T_NRST_SWD: U6.18 (PB0); also elsewhere on the board
T_NRST_SWIM: U6.42 (PB6); also elsewhere on the board
T_NRST_SWIM_IN: U6.41 (PB5); also elsewhere on the board
T_SWDCLK: U6.15 (PA5), U6.26 (PB13); also elsewhere on the board
T_SWDIO: U6.27 (PB14); also elsewhere on the board
T_SWDIO_IN: U6.25 (PB12); also elsewhere on the board
T_SWIM: U6.22 (PB11), U6.45 (PB8); also elsewhere on the board
T_SWIM_IN: U6.21 (PB10), U6.43 (PB7), U6.46 (PB9); also elsewhere on the board
USB_RENUMn: U6.38 (PA15); also elsewhere on the board

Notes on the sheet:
Self Programming
Just in case to convert into Black Magic Probe
Second microcontroller is added for possibility to use different package. Solder one microcontroller only.

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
Board: 2 copper layers, 62 parts (19 on the bottom side), 53 nets, no tracks yet.

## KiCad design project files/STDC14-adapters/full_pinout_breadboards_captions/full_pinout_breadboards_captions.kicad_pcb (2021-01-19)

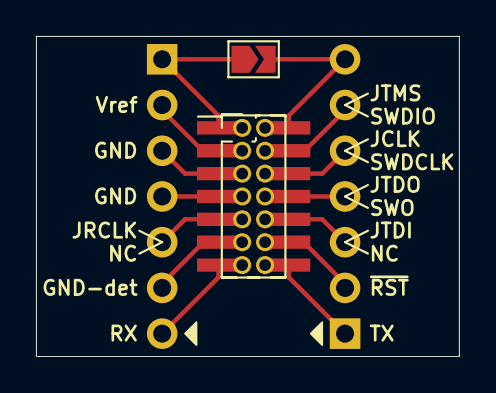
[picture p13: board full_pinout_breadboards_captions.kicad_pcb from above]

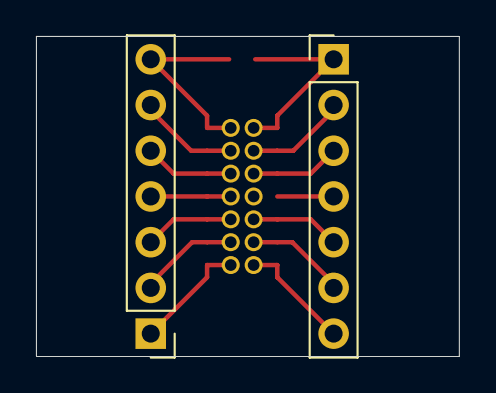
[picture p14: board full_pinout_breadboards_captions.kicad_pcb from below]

Board: 2 copper layers, 23.5 x 17.8 mm, 5 parts (2 on the bottom side), 13 nets.

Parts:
J1: STDC14_SMD; PinHeader_2x07_P1.27mm_Vertical_SMD
J2: STDC14_THT; PinHeader_2x07_P1.27mm_Vertical
J3: 1; PinHeader_1x07_P2.54mm_Vertical
J4: 2; PinHeader_1x07_P2.54mm_Vertical
JP1: Reserved; SolderJumper-2_P1.3mm_Open_TrianglePad1.0x1.5mm

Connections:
GND: J1.5, J1.7, J2.5, J2.7, J3.3, J3.4
GND_detect: J1.11, J2.11, J3.6
JCLK_SWDCLK: J1.6, J2.6, J4.5
JRCLK_NC: J1.9, J2.9, J3.5
JTDI_NC: J1.10, J2.10, J4.3
JTDO_SWO: J1.8, J2.8, J4.4
JTMS_SWDIO: J1.4, J2.4, J4.6
NRST: J1.12, J2.12, J4.2
unnamed: J1.1, J2.1, J3.1
unnamed: J1.2, J2.2, J4.7
RX: J1.13, J2.13, J3.7
TX: J1.14, J2.14, J4.1
Vref: J1.3, J2.3, J3.2

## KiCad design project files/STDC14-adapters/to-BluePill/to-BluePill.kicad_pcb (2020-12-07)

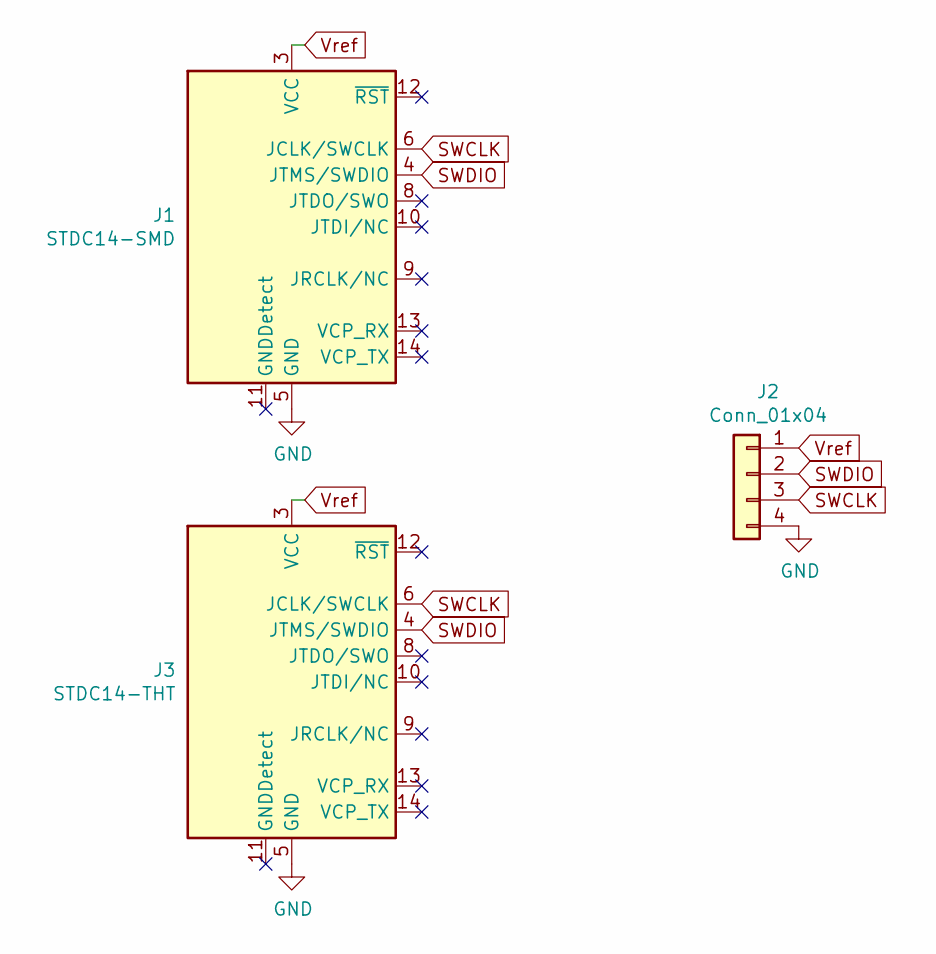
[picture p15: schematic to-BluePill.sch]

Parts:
J1: STDC14-SMD; PinHeader_2x07_P1.27mm_Vertical_SMD
J2: Conn_01x04; PinSocket_1x04_P2.54mm_Horizontal
J3: STDC14-THT; PinHeader_2x07_P1.27mm_Vertical

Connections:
GND: J1.5 (GND), J1.7 (GND), J2.4, J3.5 (GND), J3.7 (GND)
SWCLK: J1.6 (JCLK/SWCLK), J2.3, J3.6 (JCLK/SWCLK)
SWDIO: J1.4 (JTMS/SWDIO), J2.2, J3.4 (JTMS/SWDIO)
Vref: J1.3 (VCC), J2.1, J3.3 (VCC)

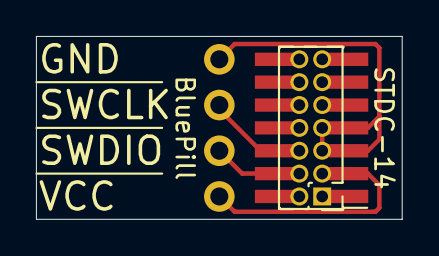
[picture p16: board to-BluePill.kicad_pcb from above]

Board: 2 copper layers, 20.3 x 10.2 mm, 3 parts (1 on the bottom side), 4 nets.

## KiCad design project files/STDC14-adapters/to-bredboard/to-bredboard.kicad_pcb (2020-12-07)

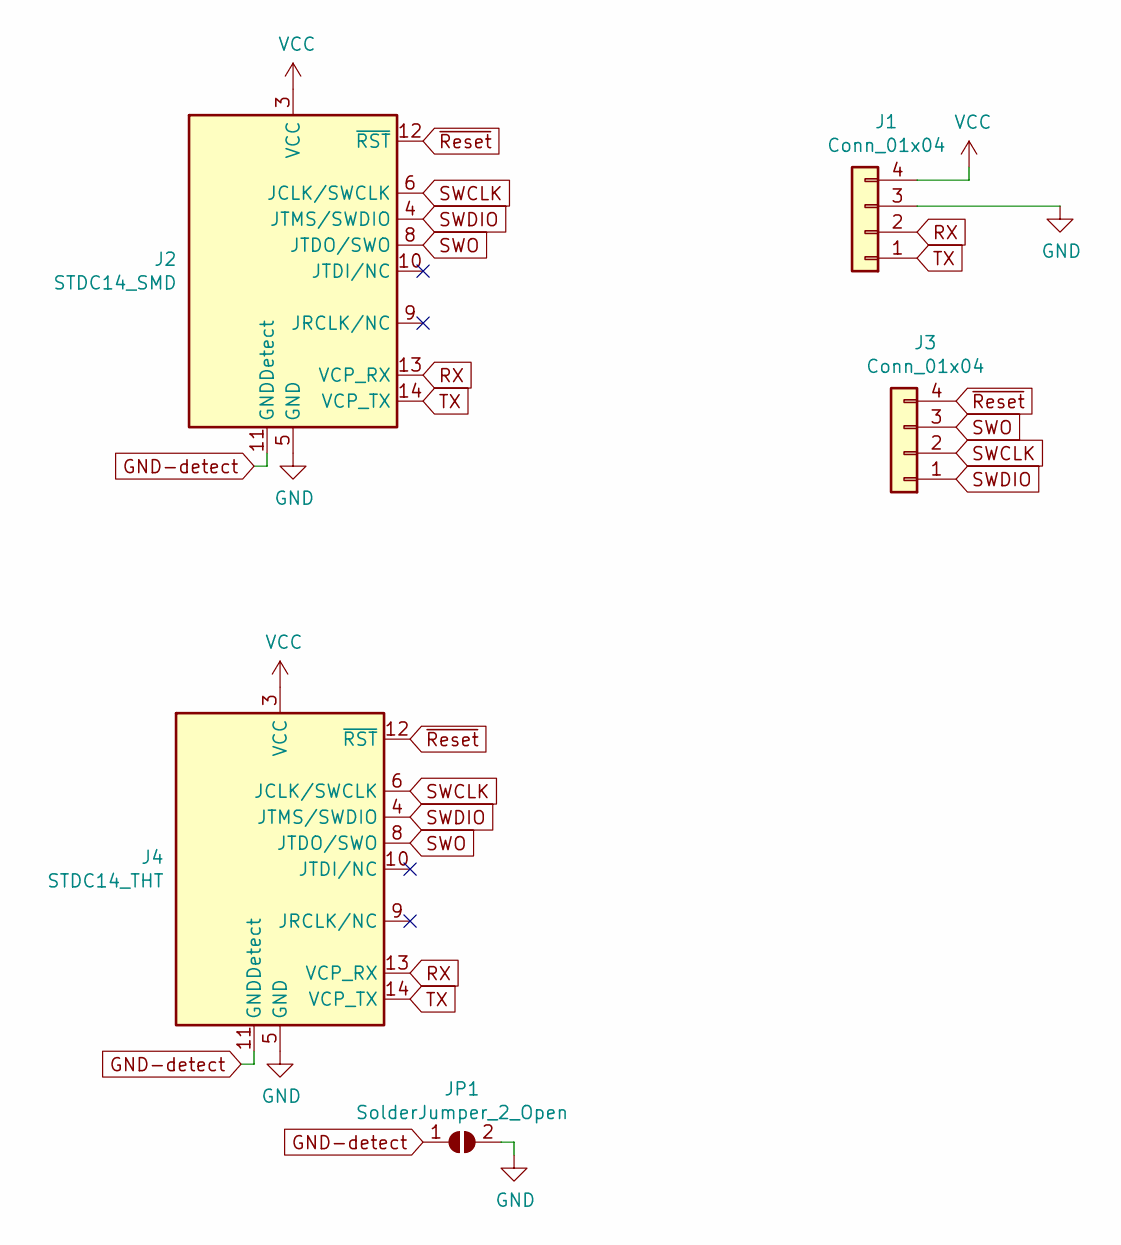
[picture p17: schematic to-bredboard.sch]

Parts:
J1, J3: Conn_01x04; PinHeader_1x04_P2.54mm_Vertical
J2: STDC14_SMD; PinHeader_2x07_P1.27mm_Vertical_SMD
J4: STDC14_THT; PinHeader_2x07_P1.27mm_Vertical
JP1: SolderJumper_2_Open; SolderJumper-2_P1.3mm_Open_TrianglePad1.0x1.5mm

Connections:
GND: J1.3, J2.5 (GND), J2.7 (GND), J4.5 (GND), J4.7 (GND), JP1.2 (B)
GND-detect: J2.11 (GNDDetect), J4.11 (GNDDetect), JP1.1 (A)
RX: J1.2, J2.13 (VCP_RX), J4.13 (VCP_RX)
SWCLK: J2.6 (JCLK/SWCLK), J3.2, J4.6 (JCLK/SWCLK)
SWDIO: J2.4 (JTMS/SWDIO), J3.1, J4.4 (JTMS/SWDIO)
SWO: J2.8 (JTDO/SWO), J3.3, J4.8 (JTDO/SWO)
TX: J1.1, J2.14 (VCP_TX), J4.14 (VCP_TX)
VCC: J1.4, J2.3 (VCC), J4.3 (VCC)
~Reset: J2.12 (~RST), J3.4, J4.12 (~RST)

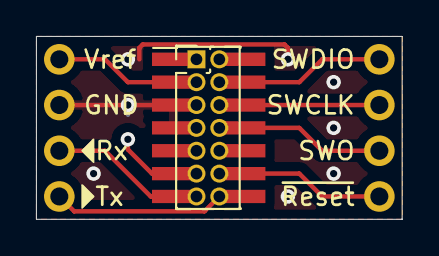
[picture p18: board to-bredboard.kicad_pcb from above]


Board: 2 copper layers, 20.3 x 10.2 mm, 5 parts (3 on the bottom side), 9 nets.

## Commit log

2020-01-07 first draft
    [stlink.kicad_pcb, stlink.sch]
2020-01-07 updates + references
    [stlink.sch]
2020-01-07 Added STDC14
    [stlink.sch]
2020-02-12 Added JTAG to STDC14
    [stlink.kicad_pcb, stlink.sch]
2020-04-15 USB Type C shield fix
    [stlink.kicad_pcb, stlink.sch]
2020-04-17 Added possibility to power target from programmer
    [stlink.kicad_pcb, stlink.sch]
2020-04-17 minor tracing
    [stlink.kicad_pcb, stlink.sch]
2020-04-20 new references
    [stlink.kicad_pcb, stlink.sch]
2020-05-09 added reference for BMP
    [stlink.kicad_pcb, stlink.sch]
2020-05-18 multi-sheet introduction for spare parts
    [spare connectivity.sch, stlink.kicad_pcb, stlink.sch]
2020-06-19 some rerouting
    [spare connectivity.sch, stlink.kicad_pcb, stlink.sch]
2020-07-22 updates with level converters
    [spare connectivity.sch, stlink.sch]
2020-11-05 fix after re-open in last KiCAD
    [stlink.sch]
2020-12-07 Added STDC-14 adaptors
    [to-BluePill.kicad_pcb, to-BluePill.sch, to-bredboard.kicad_pcb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]
2020-12-09 Self RX/TX fix
    [spare connectivity.sch, stlink.kicad_pcb]
2021-01-19 STDC adapters
    [full_pinout_breadboards.kicad_pcb, full_pinout_breadboards.sch, full_pinout_breadboards_captions.kicad_pcb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]
2021-06-06 re-opened with kicad 5.99
    [spare connectivity.kicad_sch, spare connectivity.sch, stlink.kicad_sch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]
2021-10-08 edited labels according to kicad 5.99
    [spare connectivity.kicad_sch, stlink.kicad_pcb, stlink.kicad_sch]
2021-10-08 reopened with fresher kicad
    [spare connectivity.kicad_sch, stlink.kicad_sch]
